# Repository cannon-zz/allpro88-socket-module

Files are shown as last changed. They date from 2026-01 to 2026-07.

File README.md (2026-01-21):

# KiCad Model of Logical Devices' ALLPRO88 PLCC Socket Module

## Overview

This provides a KiCad [schematic](https://github.com/user-attachments/files/24761395/socket_module_plcc_schematic.pdf) of the PLCC socket module for use with Logic Devices' ALLPRO88 software-driven device programmer.  The service manual scans available on the internet are incomprehensible.  I believe the schematic is correct.  The PCB's size and the locations of the DIN connectors, 48 pin ZIF connector and decoupling capacitors and transistors all match the original.  All other part locations are approximate, the PCB has not been routed, and the footprints for the PLCC sockets are not correct.  The PLCC sockets here have the wrong hole pattern, and are mirrored with respect to the originals.  The original module used Yamaichi IC120 series sockets, the "dead bug" variants (for which the chips are inserted upside down).  See a datasheet for the correct hole patterns.  The objective is not to allow a PLCC socket module to be reproduced from this project, but to provide a starting point for making a custom socket module.

## Board Size

Measuring my PCB to the nearest 0.5 mm, the PCB is 25.70 cm x 20.45 cm.

If it's imperial, and we allow some +/- for the saw cut accuracy, it could be 10 1/8" x 8" (= 25.7175 cm x 20.32 cm).

I found a comment in the service manual that the PCB is 10.100" x 8.05x" (x is unreadable, could be 0, 6 or 8 maybe).  0.001" = 0.0254 mm, so I don't think it really matters if that digit is a 0 or an 8.  10.1" x 8.05" = 25.65 cm x 20.45 cm which is within 0.5 mm of my measurements.

## DIN Connector Placement

From the corner of the PCB closest to the 44 pin PLCC socket, I mesaure pin C32 of J1 to be 100.8 mm horizontally from that corner, and 67.2 mm vertically.  The two DIN connectors appear to be positioned with respect to each other on a 2.54 mm grid:  A1 to A1 is 18 * 2.54 mm = 45.72 mm.  The status LEDs and their resistors appear to be on a 2.54 mm grid, centred between the DIN connectors

I suggest plugging the DIN connectors into the base, then placing the PCB onto them and either tightening the screws to hold them in that position or soldering enough pins to secure them, then removing the PCB with the connectors to continue soldering.  That way they're guaranteed to be aligned with their sockets after being soldered into position.

## Signal Names

The scans available on the internet of the original schematic, both for the socket module and the programmer's mother board, are incomprehensible.  Also, there are several inconsistent channel numbering schemes in Logical Devices' original documentation.  So:  what's here is my own invention.  Make of it what you will.

 * GND:  system power supply return.
 * -8 V, -5 V, +5 V, +12V, VREF:  main system power supplies.
 * VADJ:  main programmable, high current, power supply.  All pin driver voltages are derived from this.
 * VSR, VTH, VPU, ILIN:  pin driver power supplies.
 * !SOCKETEN:  active-low device select line indicating that the address bus is in the range 0x0280 to 0x02ff inclusively.  This is a 128 byte window reserved for the socket module.  On the universal PLCC module, reading from any address in this range returns the socket module ID, while writing to addresses in this range control the registers used to switch the pin decoupling capacitors on and off.
 * \phi_{0}, \phi_{1}:  the two phases used for driving the TTL clock output modes of the pin drivers.  When they are active they are guaranteed to be 180 degrees out of phase, but they can become inactive and enter the same state.
 * !XFER:  active low line to clock the pin driver DACs
 * !RD, !WR:  active low read- and write-enable signals.
 * !LED_BUSY, LED_IDLE:  common collector drives for the busy (red) and idle (green) LEDs.
 * !RESET:  active low system reset.  On the PLCC module, resets the decoupling capacitor registers to 0 (capacitors disconnected).
 * !SELECT0 -- !SELECT4:  active low device select lines for the first 5 pin driver modules, corresponding to channels 0 through 39 inclusively.  The ALLPRO88 was preceded by an earlier product that had only 40 channels, and it was presumably thought to be handy to have these signals brought out to the socket module to avoid duplicating address decoding circuitry in the event that lots of complex pin driver circuitry was needed for some part.
 * A0 -- A9:  partial system address bus.  The system address bus is 12 bits, but only the low 10 are present on the socket module.  Together with !SOCKETEN, only A0--A6 are needed to address the 128 byte window reserved for the socket module.
 * D0 -- D7:  system data bus.
 * OUT0 -- OUT87:  the 88 pin driver inputs/outputs.
 * SPARE1:  unused signal line that connects to the socket module, all pin driver boards, and both analogue 1 and analogue 2.  There are two unused voltage DACs on analogue 2, and I think a sensible thing to do would be to jumper one of them to this in line, to provide an additional programmable voltage to the system.  For example, the fixed 5 V linear regulators that generate the "TTL" output voltage on the pin driver boards could be replaced with adjustable regulators programmed by this voltage, making it easier to support non- 5 V logic.

## PAL

The PAL device is a look-up table for chip select line decoding.  To (I assume) simplify trace routing, pin driver channels are connected to ZIF socket pins close to their location on the DIN connector, in groups of 8 with 4 on one side of the socket and 4 on the other, while decoupling capacitor transistor drivers are connected to transistors sequentially along each side of the socket.  Additionally, for (again I assume) historical reasons only the first 40 channels have sequential addresses, the final 8 are offset at slightly higher addresses.  Altogther, these conditions create a somewhat complex relationship between the numerical address on the address bus and which transistor on which FET chip should be turned on or off, which motivates the use of a programmable logic device.

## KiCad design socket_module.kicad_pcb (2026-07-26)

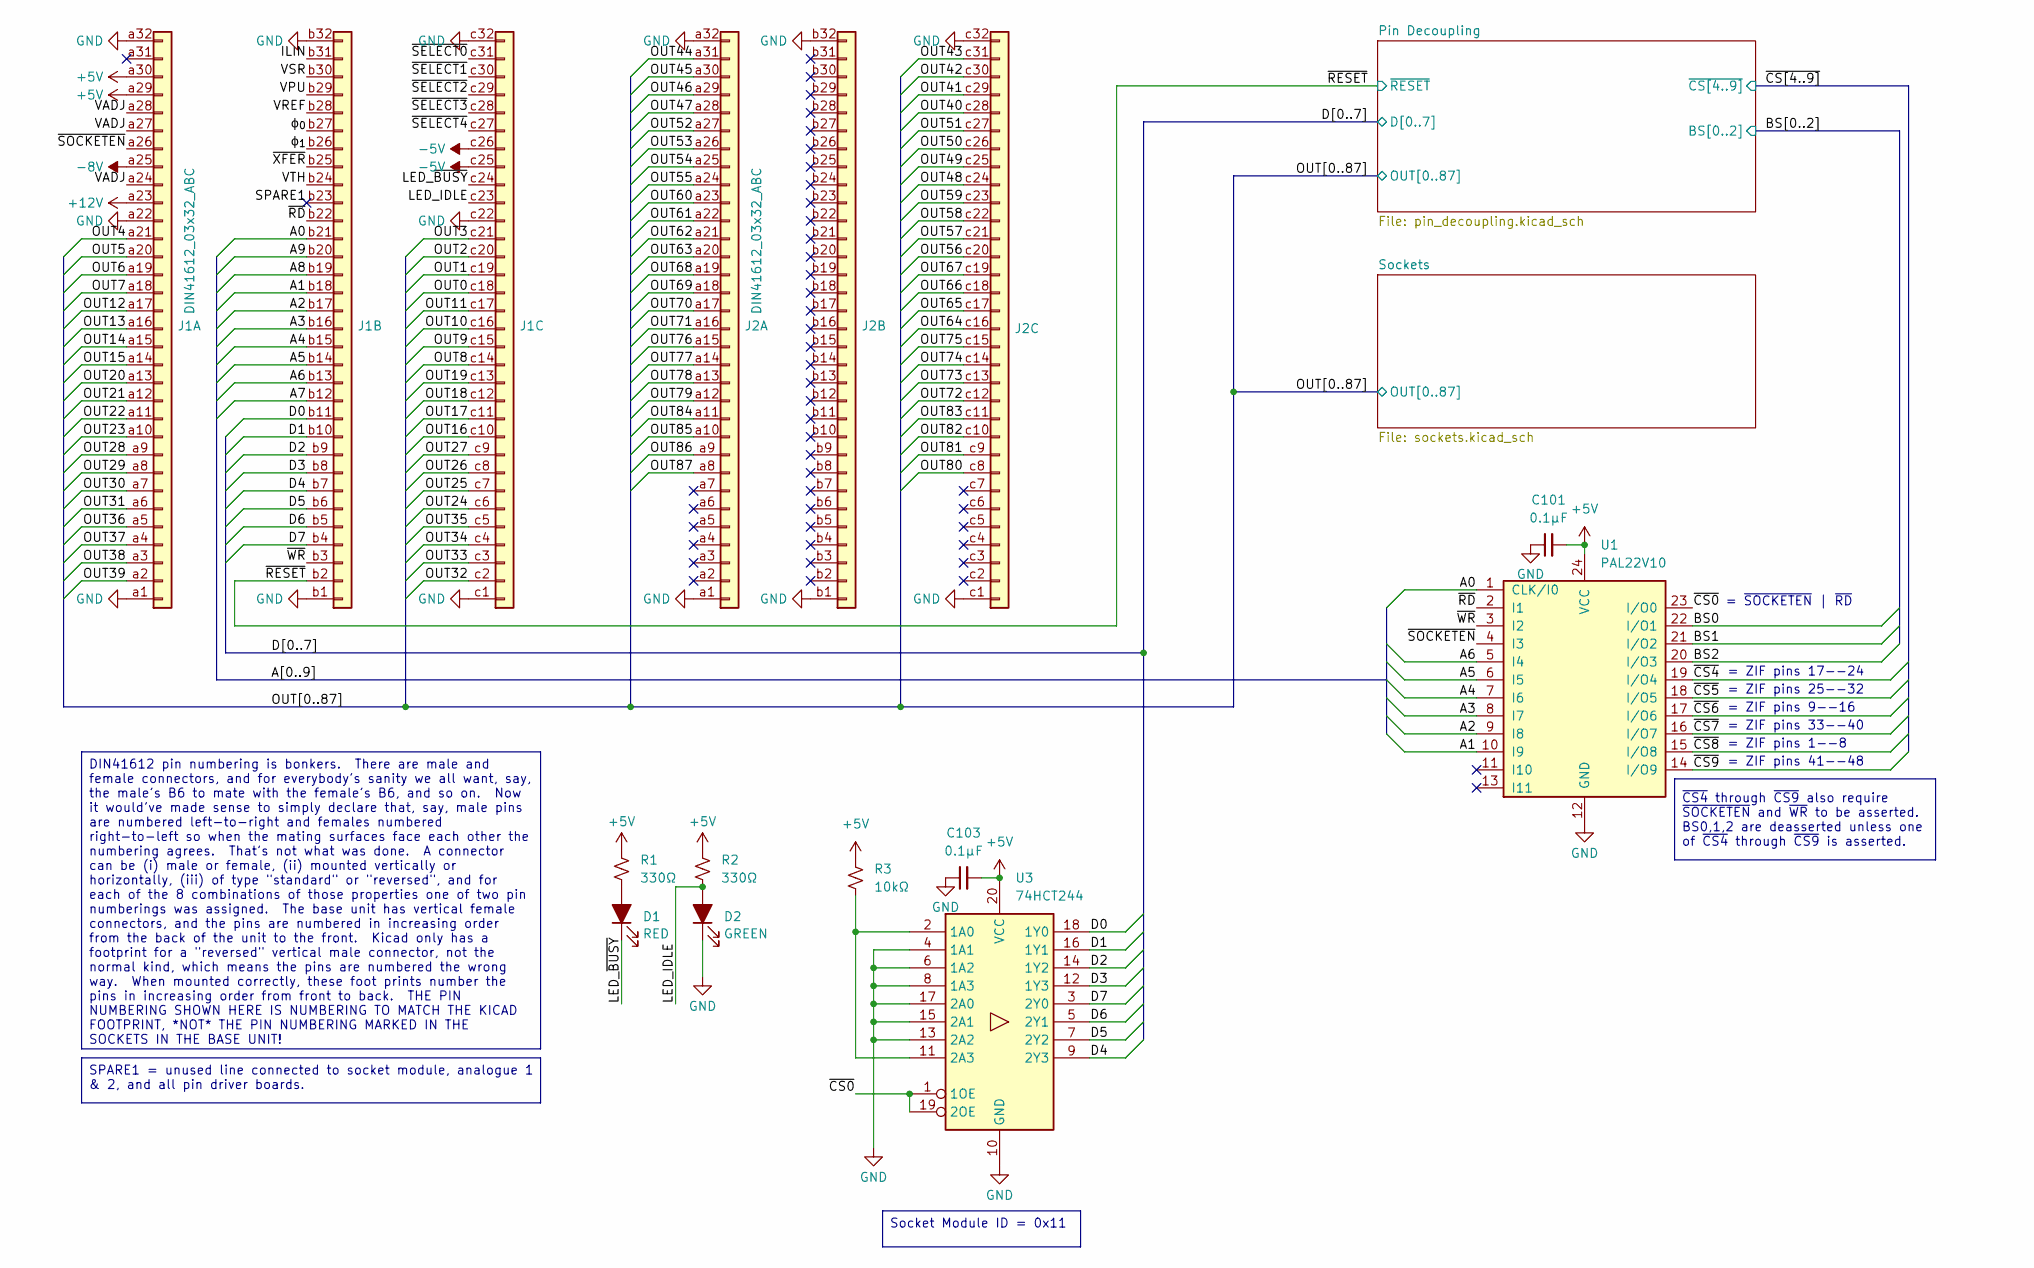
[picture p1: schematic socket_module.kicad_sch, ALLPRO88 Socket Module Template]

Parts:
C101, C103: 0.1μF; C_Disc_D7.5mm_W2.5mm_P5.00mm
D1: RED; LED_Rectangular_W5.0mm_H2.0mm
D2: GREEN; LED_Rectangular_W5.0mm_H2.0mm
J1, J2: DIN41612_03x32_ABC; DIN41612_R_3x32_Male_Vertical_THT
R1, R2: 330Ω; R_Axial_DIN0207_L6.3mm_D2.5mm_P10.16mm_Horizontal
R3: 10kΩ; R_Axial_DIN0207_L6.3mm_D2.5mm_P10.16mm_Horizontal
U1: PAL22V10; DIP-24_W7.62mm_Socket_LongPads
U3: 74HCT244; DIP-20_W7.62mm_LongPads

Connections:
+5V: C101.2, C103.2, J1.a29, J1.a30, R1.1, R2.1, R3.1, U1.24 (VCC), U3.20 (VCC); also elsewhere on the board
+12V: J1.a23
-5V: J1.c25, J1.c26
-8V: J1.a25
/A0: J1.b21, U1.1 (CLK/I0)
/A1: J1.b18, U1.10 (I9)
/A2: J1.b17, U1.9 (I8)
/A3: J1.b16, U1.8 (I7)
/A4: J1.b15, U1.7 (I6)
/A5: J1.b14, U1.6 (I5)
/A6: J1.b13, U1.5 (I4)
/A7: J1.b12
/A8: J1.b19
/A9: J1.b20
/BS0: U1.22 (I/O1); also elsewhere on the board
/BS1: U1.21 (I/O2); also elsewhere on the board
/BS2: U1.20 (I/O3); also elsewhere on the board
/D0: J1.b11, U3.18 (1Y0); also elsewhere on the board
/D1: J1.b10, U3.16 (1Y1)
/D2: J1.b9, U3.14 (1Y2)
/D3: J1.b8, U3.12 (1Y3)
/D4: J1.b7, U3.9 (2Y3)
/D5: J1.b6, U3.7 (2Y2)
/D6: J1.b5, U3.5 (2Y1)
/D7: J1.b4, U3.3 (2Y0)
/ILIN: J1.b31
/LED_IDLE: D2.2 (A), J1.c23, R2.2
/LED_~BUSY: D1.1 (K), J1.c24
/OUT0: J1.c18; also elsewhere on the board
/OUT1: J1.c19; also elsewhere on the board
/OUT2: J1.c20; also elsewhere on the board
/OUT3: J1.c21; also elsewhere on the board
/OUT4: J1.a21; also elsewhere on the board
/OUT5: J1.a20; also elsewhere on the board
/OUT6: J1.a19; also elsewhere on the board
/OUT7: J1.a18; also elsewhere on the board
/OUT8: J1.c14; also elsewhere on the board
/OUT9: J1.c15; also elsewhere on the board
/OUT10: J1.c16; also elsewhere on the board
/OUT11: J1.c17; also elsewhere on the board
/OUT12: J1.a17; also elsewhere on the board
/OUT13: J1.a16; also elsewhere on the board
/OUT14: J1.a15; also elsewhere on the board
/OUT15: J1.a14; also elsewhere on the board
/OUT16: J1.c10; also elsewhere on the board
/OUT17: J1.c11; also elsewhere on the board
/OUT18: J1.c12; also elsewhere on the board
/OUT19: J1.c13; also elsewhere on the board
/OUT20: J1.a13; also elsewhere on the board
/OUT21: J1.a12; also elsewhere on the board
/OUT22: J1.a11; also elsewhere on the board
/OUT23: J1.a10; also elsewhere on the board
/OUT24: J1.c6; also elsewhere on the board
/OUT25: J1.c7; also elsewhere on the board
/OUT26: J1.c8; also elsewhere on the board
/OUT27: J1.c9; also elsewhere on the board
/OUT28: J1.a9; also elsewhere on the board
/OUT29: J1.a8; also elsewhere on the board
/OUT30: J1.a7; also elsewhere on the board
/OUT31: J1.a6; also elsewhere on the board
/OUT32: J1.c2; also elsewhere on the board
/OUT33: J1.c3; also elsewhere on the board
/OUT34: J1.c4; also elsewhere on the board
/OUT35: J1.c5; also elsewhere on the board
/OUT36: J1.a5; also elsewhere on the board
/OUT37: J1.a4; also elsewhere on the board
/OUT38: J1.a3; also elsewhere on the board
/OUT39: J1.a2; also elsewhere on the board
/OUT40: J2.c28; also elsewhere on the board
/OUT41: J2.c29; also elsewhere on the board
/OUT42: J2.c30; also elsewhere on the board
/OUT43: J2.c31; also elsewhere on the board
/OUT44: J2.a31; also elsewhere on the board
/OUT45: J2.a30; also elsewhere on the board
/OUT46: J2.a29; also elsewhere on the board
/OUT47: J2.a28; also elsewhere on the board
/OUT48: J2.c24; also elsewhere on the board
/OUT49: J2.c25; also elsewhere on the board
/OUT50: J2.c26; also elsewhere on the board
/OUT51: J2.c27; also elsewhere on the board
/OUT52: J2.a27; also elsewhere on the board
/OUT53: J2.a26; also elsewhere on the board
/OUT54: J2.a25; also elsewhere on the board
/OUT55: J2.a24; also elsewhere on the board
/OUT56: J2.c20; also elsewhere on the board
/OUT57: J2.c21; also elsewhere on the board
/OUT58: J2.c22; also elsewhere on the board
/OUT59: J2.c23; also elsewhere on the board
/OUT60: J2.a23; also elsewhere on the board
/OUT61: J2.a22; also elsewhere on the board
/OUT62: J2.a21; also elsewhere on the board
/OUT63: J2.a20; also elsewhere on the board
/OUT64: J2.c16; also elsewhere on the board
/OUT65: J2.c17; also elsewhere on the board
/OUT66: J2.c18; also elsewhere on the board
/OUT67: J2.c19; also elsewhere on the board
/OUT68: J2.a19; also elsewhere on the board
/OUT69: J2.a18; also elsewhere on the board
/OUT70: J2.a17; also elsewhere on the board
/OUT71: J2.a16; also elsewhere on the board
/OUT72: J2.c12; also elsewhere on the board
/OUT73: J2.c13; also elsewhere on the board
/OUT74: J2.c14; also elsewhere on the board
/OUT75: J2.c15; also elsewhere on the board
/OUT76: J2.a15; also elsewhere on the board
/OUT77: J2.a14; also elsewhere on the board
/OUT78: J2.a13; also elsewhere on the board
/OUT79: J2.a12; also elsewhere on the board
/OUT80: J2.c8
/OUT81: J2.c9
/OUT82: J2.c10; also elsewhere on the board
/OUT83: J2.c11; also elsewhere on the board
/OUT84: J2.a11; also elsewhere on the board
/OUT85: J2.a10; also elsewhere on the board
/OUT86: J2.a9
/OUT87: J2.a8
/SPARE1: J1.b23
/VADJ: J1.a24, J1.a27, J1.a28
/VPU: J1.b29
/VREF: J1.b28
/VSR: J1.b30
/VTH: J1.b24 (Pin_a24)
/~CS0: U1.23 (I/O0), U3.1 (1OE), U3.19 (2OE)
/~CS4: U1.19 (I/O4); also elsewhere on the board
/~CS5: U1.18 (I/O5); also elsewhere on the board
/~CS6: U1.17 (I/O6); also elsewhere on the board
/~CS7: U1.16 (I/O7); also elsewhere on the board
/~CS8: U1.15 (I/O8); also elsewhere on the board
/~CS9: U1.14 (I/O9); also elsewhere on the board
/~RD: J1.b22, U1.2 (I1)
/~RESET: J1.b2; also elsewhere on the board
/~SELECT0: J1.c31
/~SELECT1: J1.c30
/~SELECT2: J1.c29
/~SELECT3: J1.c28
/~SELECT4: J1.c27
/~SOCKETEN: J1.a26, U1.4 (I3)
/~WR: J1.b3, U1.3 (I2)
/~XFER: J1.b25
/ϕ_{0}: J1.b27
/ϕ_{1}: J1.b26
GND: C101.1, C103.1, D2.1 (K), J1.a1, J1.a22, J1.a32, J1.b1, J1.b32, J1.c1, J1.c22, J1.c32, J2.a1, J2.a32, J2.b1, J2.b32, J2.c1, J2.c32, U1.12 (GND), U3.4 (1A1), U3.6 (1A2), U3.8 (1A3), U3.10 (GND), U3.13 (2A2), U3.15 (2A1), U3.17 (2A0); also elsewhere on the board
unnamed: D1.2 (A), R1.2
unnamed: R3.2, U3.2 (1A0), U3.11 (2A3)

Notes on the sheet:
= ZIF pins 33--40
= ~{SOCKETEN} | ~{RD}
= ZIF pins 17--24
= ZIF pins 41--48
= ZIF pins 1--8
= ZIF pins 25--32
= ZIF pins 9--16
~{CS4} through ~{CS9} also require ~{SOCKETEN} and ~{WR} to be asserted. BS0,1,2 are deasserted unless one of ~{CS4} through ~{CS9} is asserted.
Socket Module ID = 0x11
DIN41612 pin numbering is bonkers. There are male and female connectors, and for everybody's sanity we all want, say, the male's B6 to mate with the female's B6, and so on. Now it would've made sense to simply declare that, say, male pins are numbered left-to-right and females numbered right-to-lef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
SPARE1 = unused line connected to socket module, analogue 1 & 2, and all pin driver boards.

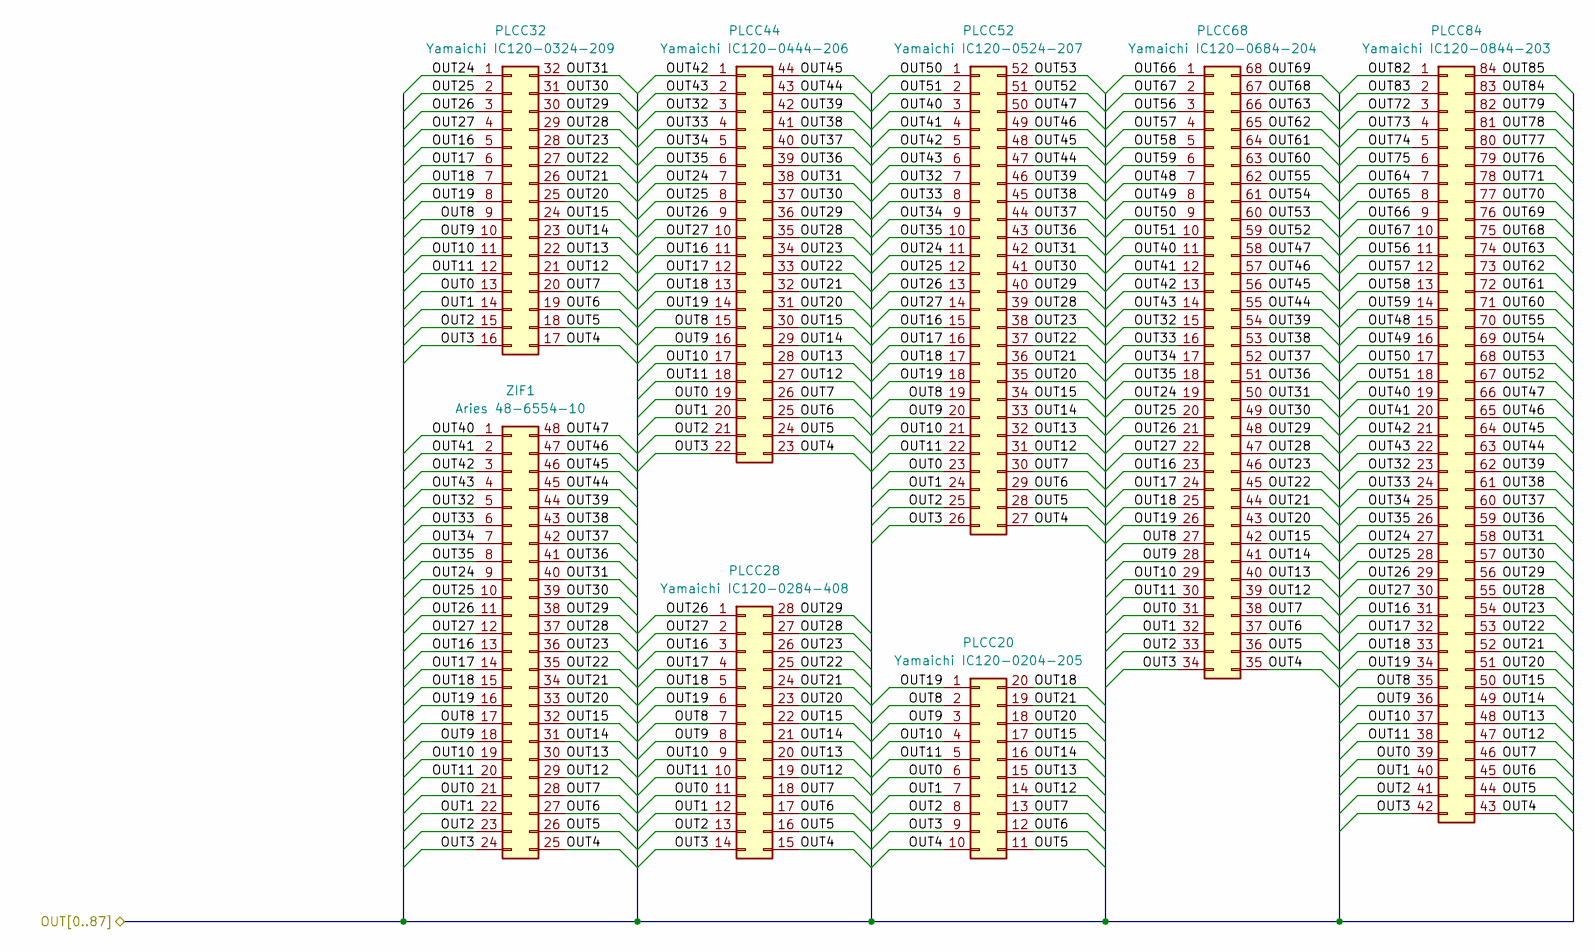
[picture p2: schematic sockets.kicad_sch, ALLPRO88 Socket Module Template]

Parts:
PLCC20: Yamaichi IC120-0204-205; PLCC-20_THT-Socket
PLCC28: Yamaichi IC120-0284-408; PLCC-28_THT-Socket
PLCC32: Yamaichi IC120-0324-209; PLCC-32_THT-Socket
PLCC44: Yamaichi IC120-0444-206; PLCC-44_THT-Socket
PLCC52: Yamaichi IC120-0524-207; PLCC-52_THT-Socket
PLCC68: Yamaichi IC120-0684-204; PLCC-68_THT-Socket
PLCC84: Yamaichi IC120-0844-203; PLCC-84_THT-Socket
ZIF1: Aries 48-6554-10; DIP-48_W15.24mm_Socket_LongPads

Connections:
/OUT0: PLCC20.6, PLCC28.11, PLCC32.13, PLCC44.19, PLCC52.23, PLCC68.31, PLCC84.39, ZIF1.21; also elsewhere on the board
/OUT1: PLCC20.7, PLCC28.12, PLCC32.14, PLCC44.20, PLCC52.24, PLCC68.32, PLCC84.40, ZIF1.22; also elsewhere on the board
/OUT2: PLCC20.8, PLCC28.13, PLCC32.15, PLCC44.21, PLCC52.25, PLCC68.33, PLCC84.41, ZIF1.23; also elsewhere on the board
/OUT3: PLCC20.9, PLCC28.14, PLCC32.16, PLCC44.22, PLCC52.26, PLCC68.34, PLCC84.42, ZIF1.24; also elsewhere on the board
/OUT4: PLCC20.10, PLCC28.15, PLCC32.17, PLCC44.23, PLCC52.27, PLCC68.35, PLCC84.43, ZIF1.25; also elsewhere on the board
/OUT5: PLCC20.11, PLCC28.16, PLCC32.18, PLCC44.24, PLCC52.28, PLCC68.36, PLCC84.44, ZIF1.26; also elsewhere on the board
/OUT6: PLCC20.12, PLCC28.17, PLCC32.19, PLCC44.25, PLCC52.29, PLCC68.37, PLCC84.45, ZIF1.27; also elsewhere on the board
/OUT7: PLCC20.13, PLCC28.18, PLCC32.20, PLCC44.26, PLCC52.30, PLCC68.38, PLCC84.46, ZIF1.28; also elsewhere on the board
/OUT8: PLCC20.2, PLCC28.7, PLCC32.9, PLCC44.15, PLCC52.19, PLCC68.27, PLCC84.35, ZIF1.17; also elsewhere on the board
/OUT9: PLCC20.3, PLCC28.8, PLCC32.10, PLCC44.16, PLCC52.20, PLCC68.28, PLCC84.36, ZIF1.18; also elsewhere on the board
/OUT10: PLCC20.4, PLCC28.9, PLCC32.11, PLCC44.17, PLCC52.21, PLCC68.29, PLCC84.37, ZIF1.19; also elsewhere on the board
/OUT11: PLCC20.5, PLCC28.10, PLCC32.12, PLCC44.18, PLCC52.22, PLCC68.30, PLCC84.38, ZIF1.20; also elsewhere on the board
/OUT12: PLCC20.14, PLCC28.19, PLCC32.21, PLCC44.27, PLCC52.31, PLCC68.39, PLCC84.47, ZIF1.29; also elsewhere on the board
/OUT13: PLCC20.15, PLCC28.20, PLCC32.22, PLCC44.28, PLCC52.32, PLCC68.40, PLCC84.48, ZIF1.30; also elsewhere on the board
/OUT14: PLCC20.16, PLCC28.21, PLCC32.23, PLCC44.29, PLCC52.33, PLCC68.41, PLCC84.49, ZIF1.31; also elsewhere on the board
/OUT15: PLCC20.17, PLCC28.22, PLCC32.24, PLCC44.30, PLCC52.34, PLCC68.42, PLCC84.50, ZIF1.32; also elsewhere on the board
/OUT16: PLCC28.3, PLCC32.5, PLCC44.11, PLCC52.15, PLCC68.23, PLCC84.31, ZIF1.13; also elsewhere on the board
/OUT17: PLCC28.4, PLCC32.6, PLCC44.12, PLCC52.16, PLCC68.24, PLCC84.32, ZIF1.14; also elsewhere on the board
/OUT18: PLCC20.20, PLCC28.5, PLCC32.7, PLCC44.13, PLCC52.17, PLCC68.25, PLCC84.33, ZIF1.15; also elsewhere on the board
/OUT19: PLCC20.1, PLCC28.6, PLCC32.8, PLCC44.14, PLCC52.18, PLCC68.26, PLCC84.34, ZIF1.16; also elsewhere on the board
/OUT20: PLCC20.18, PLCC28.23, PLCC32.25, PLCC44.31, PLCC52.35, PLCC68.43, PLCC84.51, ZIF1.33; also elsewhere on the board
/OUT21: PLCC20.19, PLCC28.24, PLCC32.26, PLCC44.32, PLCC52.36, PLCC68.44, PLCC84.52, ZIF1.34; also elsewhere on the board
/OUT22: PLCC28.25, PLCC32.27, PLCC44.33, PLCC52.37, PLCC68.45, PLCC84.53, ZIF1.35; also elsewhere on the board
/OUT23: PLCC28.26, PLCC32.28, PLCC44.34, PLCC52.38, PLCC68.46, PLCC84.54, ZIF1.36; also elsewhere on the board
/OUT24: PLCC32.1, PLCC44.7, PLCC52.11, PLCC68.19, PLCC84.27, ZIF1.9; also elsewhere on the board
/OUT25: PLCC32.2, PLCC44.8, PLCC52.12, PLCC68.20, PLCC84.28, ZIF1.10; also elsewhere on the board
/OUT26: PLCC28.1, PLCC32.3, PLCC44.9, PLCC52.13, PLCC68.21, PLCC84.29, ZIF1.11; also elsewhere on the board
/OUT27: PLCC28.2, PLCC32.4, PLCC44.10, PLCC52.14, PLCC68.22, PLCC84.30, ZIF1.12; also elsewhere on the board
/OUT28: PLCC28.27, PLCC32.29, PLCC44.35, PLCC52.39, PLCC68.47, PLCC84.55, ZIF1.37; also elsewhere on the board
/OUT29: PLCC28.28, PLCC32.30, PLCC44.36, PLCC52.40, PLCC68.48, PLCC84.56, ZIF1.38; also elsewhere on the board
/OUT30: PLCC32.31, PLCC44.37, PLCC52.41, PLCC68.49, PLCC84.57, ZIF1.39; also elsewhere on the board
/OUT31: PLCC32.32, PLCC44.38, PLCC52.42, PLCC68.50, PLCC84.58, ZIF1.40; also elsewhere on the board
/OUT32: PLCC44.3, PLCC52.7, PLCC68.15, PLCC84.23, ZIF1.5; also elsewhere on the board
/OUT33: PLCC44.4, PLCC52.8, PLCC68.16, PLCC84.24, ZIF1.6; also elsewhere on the board
/OUT34: PLCC44.5, PLCC52.9, PLCC68.17, PLCC84.25, ZIF1.7; also elsewhere on the board
/OUT35: PLCC44.6, PLCC52.10, PLCC68.18, PLCC84.26, ZIF1.8; also elsewhere on the board
/OUT36: PLCC44.39, PLCC52.43, PLCC68.51, PLCC84.59, ZIF1.41; also elsewhere on the board
/OUT37: PLCC44.40, PLCC52.44, PLCC68.52, PLCC84.60, ZIF1.42; also elsewhere on the board
/OUT38: PLCC44.41, PLCC52.45, PLCC68.53, PLCC84.61, ZIF1.43; also elsewhere on the board
/OUT39: PLCC44.42, PLCC52.46, PLCC68.54, PLCC84.62, ZIF1.44; also elsewhere on the board
/OUT40: PLCC52.3, PLCC68.11, PLCC84.19, ZIF1.1; also elsewhere on the board
/OUT41: PLCC52.4, PLCC68.12, PLCC84.20, ZIF1.2; also elsewhere on the board
/OUT42: PLCC44.1, PLCC52.5, PLCC68.13, PLCC84.21, ZIF1.3; also elsewhere on the board
/OUT43: PLCC44.2, PLCC52.6, PLCC68.14, PLCC84.22, ZIF1.4; also elsewhere on the board
/OUT44: PLCC44.43, PLCC52.47, PLCC68.55, PLCC84.63, ZIF1.45; also elsewhere on the board
/OUT45: PLCC44.44, PLCC52.48, PLCC68.56, PLCC84.64, ZIF1.46; also elsewhere on the board
/OUT46: PLCC52.49, PLCC68.57, PLCC84.65, ZIF1.47; also elsewhere on the board
/OUT47: PLCC52.50, PLCC68.58, PLCC84.66, ZIF1.48; also elsewhere on the board
/OUT48: PLCC68.7, PLCC84.15; also elsewhere on the board
/OUT49: PLCC68.8, PLCC84.16; also elsewhere on the board
/OUT50: PLCC52.1, PLCC68.9, PLCC84.17; also elsewhere on the board
/OUT51: PLCC52.2, PLCC68.10, PLCC84.18; also elsewhere on the board
/OUT52: PLCC52.51, PLCC68.59, PLCC84.67; also elsewhere on the board
/OUT53: PLCC52.52, PLCC68.60, PLCC84.68; also elsewhere on the board
/OUT54: PLCC68.61, PLCC84.69; also elsewhere on the board
/OUT55: PLCC68.62, PLCC84.70; also elsewhere on the board
/OUT56: PLCC68.3, PLCC84.11; also elsewhere on the board
/OUT57: PLCC68.4, PLCC84.12; also elsewhere on the board
/OUT58: PLCC68.5, PLCC84.13; also elsewhere on the board
/OUT59: PLCC68.6, PLCC84.14; also elsewhere on the board
/OUT60: PLCC68.63, PLCC84.71; also elsewhere on the board
/OUT61: PLCC68.64, PLCC84.72; also elsewhere on the board
/OUT62: PLCC68.65, PLCC84.73; also elsewhere on the board
/OUT63: PLCC68.66, PLCC84.74; also elsewhere on the board
/OUT64: PLCC84.7; also elsewhere on the board
/OUT65: PLCC84.8; also elsewhere on the board
/OUT66: PLCC68.1, PLCC84.9; also elsewhere on the board
/OUT67: PLCC68.2, PLCC84.10; also elsewhere on the board
/OUT68: PLCC68.67, PLCC84.75; also elsewhere on the board
/OUT69: PLCC68.68, PLCC84.76; also elsewhere on the board
/OUT70: PLCC84.77; also elsewhere on the board
/OUT71: PLCC84.78; also elsewhere on the board
/OUT72: PLCC84.3; also elsewhere on the board
/OUT73: PLCC84.4; also elsewhere on the board
/OUT74: PLCC84.5; also elsewhere on the board
/OUT75: PLCC84.6; also elsewhere on the board
/OUT76: PLCC84.79; also elsewhere on the board
/OUT77: PLCC84.80; also elsewhere on the board
/OUT78: PLCC84.81; also elsewhere on the board
/OUT79: PLCC84.82; also elsewhere on the board
/OUT82: PLCC84.1; also elsewhere on the board
/OUT83: PLCC84.2; also elsewhere on the board
/OUT84: PLCC84.83; also elsewhere on the board
/OUT85: PLCC84.84; also elsewhere on the board

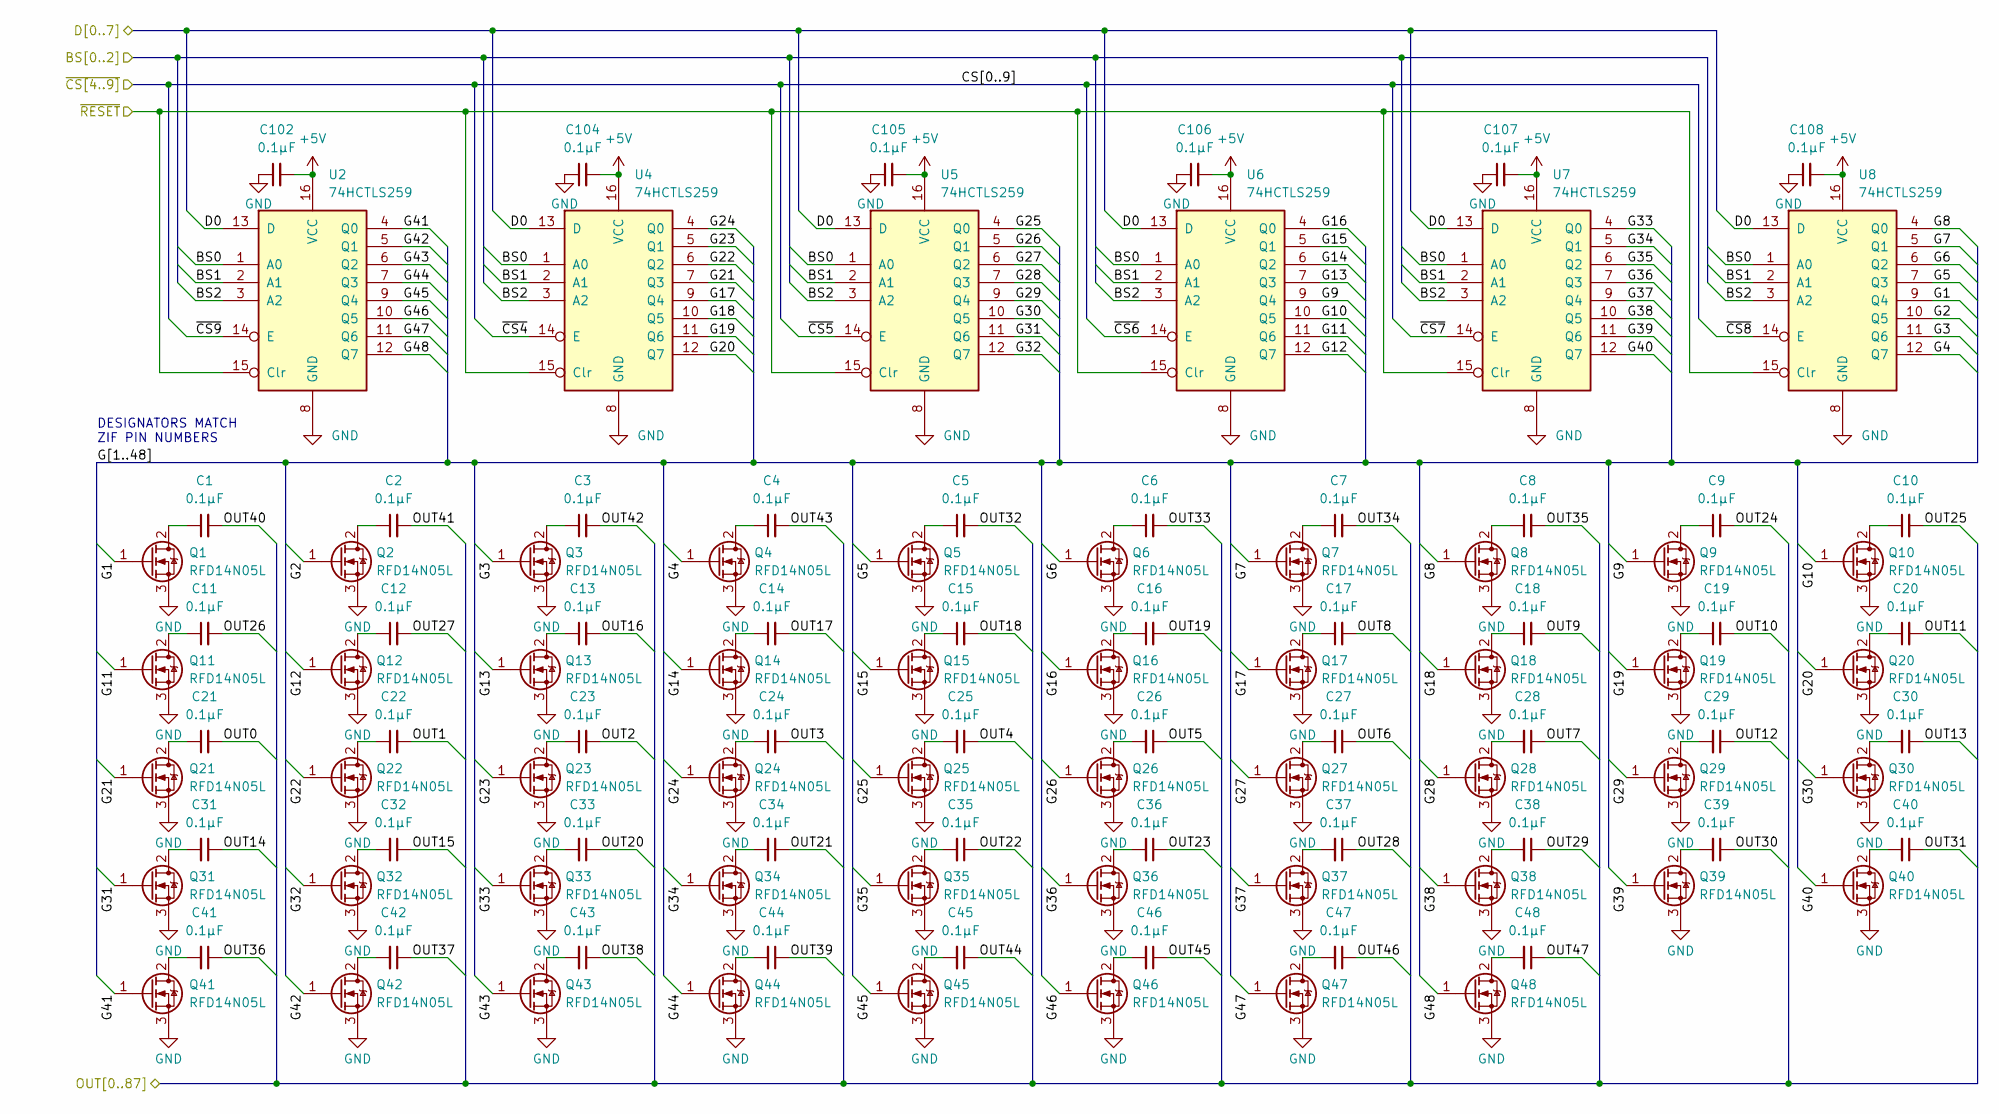
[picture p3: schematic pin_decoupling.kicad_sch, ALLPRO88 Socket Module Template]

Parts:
C1, C2, C3, C4, C5, C6, C7, C8, C9, C10, C11, C12, C13, C14, C15, C16, C17, C18, C19, C20, C21, C22, C23, C24, C25, C26, C27, C28, C29, C30, C31, C32, C33, C34, C35, C36, C37, C38, C39, C40, C41, C42, C43, C44, C45, C46, C47, C48, C102, C104, C105, C106, C107, C108: 0.1μF; C_Disc_D7.5mm_W2.5mm_P5.00mm
Q1, Q2, Q3, Q4, Q5, Q6, Q7, Q8, Q9, Q10, Q11, Q12, Q13, Q14, Q15, Q16, Q17, Q18, Q19, Q20, Q21, Q22, Q23, Q24, Q25, Q26, Q27, Q28, Q29, Q30, Q31, Q32, Q33, Q34, Q35, Q36, Q37, Q38, Q39, Q40, Q41, Q42, Q43, Q44, Q45, Q46, Q47, Q48: RFD14N05L; TO-251-3_Vertical
U2, U4, U5, U6, U7, U8: 74HCTLS259; DIP-16_W7.62mm_LongPads

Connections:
+5V: C102.2, C104.2, C105.2, C106.2, C107.2, C108.2, U2.16 (VCC), U4.16 (VCC), U5.16 (VCC), U6.16 (VCC), U7.16 (VCC), U8.16 (VCC); also elsewhere on the board
/BS0: U2.1 (A0), U4.1 (A0), U5.1 (A0), U6.1 (A0), U7.1 (A0), U8.1 (A0); also elsewhere on the board
/BS1: U2.2 (A1), U4.2 (A1), U5.2 (A1), U6.2 (A1), U7.2 (A1), U8.2 (A1); also elsewhere on the board
/BS2: U2.3 (A2), U4.3 (A2), U5.3 (A2), U6.3 (A2), U7.3 (A2), U8.3 (A2); also elsewhere on the board
/D0: U2.13 (D), U4.13 (D), U5.13 (D), U6.13 (D), U7.13 (D), U8.13 (D); also elsewhere on the board
/OUT0: C21.2; also elsewhere on the board
/OUT1: C22.2; also elsewhere on the board
/OUT2: C23.2; also elsewhere on the board
/OUT3: C24.2; also elsewhere on the board
/OUT4: C25.1; also elsewhere on the board
/OUT5: C26.1; also elsewhere on the board
/OUT6: C27.1; also elsewhere on the board
/OUT7: C28.1; also elsewhere on the board
/OUT8: C17.2; also elsewhere on the board
/OUT9: C18.2; also elsewhere on the board
/OUT10: C19.2; also elsewhere on the board
/OUT11: C20.2; also elsewhere on the board
/OUT12: C29.1; also elsewhere on the board
/OUT13: C30.1; also elsewhere on the board
/OUT14: C31.1; also elsewhere on the board
/OUT15: C32.1; also elsewhere on the board
/OUT16: C13.2; also elsewhere on the board
/OUT17: C14.2; also elsewhere on the board
/OUT18: C15.2; also elsewhere on the board
/OUT19: C16.2; also elsewhere on the board
/OUT20: C33.1; also elsewhere on the board
/OUT21: C34.1; also elsewhere on the board
/OUT22: C35.1; also elsewhere on the board
/OUT23: C36.1; also elsewhere on the board
/OUT24: C9.2; also elsewhere on the board
/OUT25: C10.2; also elsewhere on the board
/OUT26: C11.2; also elsewhere on the board
/OUT27: C12.2; also elsewhere on the board
/OUT28: C37.1; also elsewhere on the board
/OUT29: C38.1; also elsewhere on the board
/OUT30: C39.1; also elsewhere on the board
/OUT31: C40.1; also elsewhere on the board
/OUT32: C5.2; also elsewhere on the board
/OUT33: C6.2; also elsewhere on the board
/OUT34: C7.2; also elsewhere on the board
/OUT35: C8.2; also elsewhere on the board
/OUT36: C41.1; also elsewhere on the board
/OUT37: C42.1; also elsewhere on the board
/OUT38: C43.1; also elsewhere on the board
/OUT39: C44.1; also elsewhere on the board
/OUT40: C1.2; also elsewhere on the board
/OUT41: C2.2; also elsewhere on the board
/OUT42: C3.2; also elsewhere on the board
/OUT43: C4.2; also elsewhere on the board
/OUT44: C45.1; also elsewhere on the board
/OUT45: C46.1; also elsewhere on the board
/OUT46: C47.1; also elsewhere on the board
/OUT47: C48.1; also elsewhere on the board
/Pin Decoupling/G1: Q1.1 (G), U8.9 (Q4)
/Pin Decoupling/G2: Q2.1 (G), U8.10 (Q5)
/Pin Decoupling/G3: Q3.1 (G), U8.11 (Q6)
/Pin Decoupling/G4: Q4.1 (G), U8.12 (Q7)
/Pin Decoupling/G5: Q5.1 (G), U8.7 (Q3)
/Pin Decoupling/G6: Q6.1 (G), U8.6 (Q2)
/Pin Decoupling/G7: Q7.1 (G), U8.5 (Q1)
/Pin Decoupling/G8: Q8.1 (G), U8.4 (Q0)
/Pin Decoupling/G9: Q9.1 (G), U6.9 (Q4)
/Pin Decoupling/G10: Q10.1 (G), U6.10 (Q5)
/Pin Decoupling/G11: Q11.1 (G), U6.11 (Q6)
/Pin Decoupling/G12: Q12.1 (G), U6.12 (Q7)
/Pin Decoupling/G13: Q13.1 (G), U6.7 (Q3)
/Pin Decoupling/G14: Q14.1 (G), U6.6 (Q2)
/Pin Decoupling/G15: Q15.1 (G), U6.5 (Q1)
/Pin Decoupling/G16: Q16.1 (G), U6.4 (Q0)
/Pin Decoupling/G17: Q17.1 (G), U4.9 (Q4)
/Pin Decoupling/G18: Q18.1 (G), U4.10 (Q5)
/Pin Decoupling/G19: Q19.1 (G), U4.11 (Q6)
/Pin Decoupling/G20: Q20.1 (G), U4.12 (Q7)
/Pin Decoupling/G21: Q21.1 (G), U4.7 (Q3)
/Pin Decoupling/G22: Q22.1 (G), U4.6 (Q2)
/Pin Decoupling/G23: Q23.1 (G), U4.5 (Q1)
/Pin Decoupling/G24: Q24.1 (G), U4.4 (Q0)
/Pin Decoupling/G25: Q25.1 (G), U5.4 (Q0)
/Pin Decoupling/G26: Q26.1 (G), U5.5 (Q1)
/Pin Decoupling/G27: Q27.1 (G), U5.6 (Q2)
/Pin Decoupling/G28: Q28.1 (G), U5.7 (Q3)
/Pin Decoupling/G29: Q29.1 (G), U5.9 (Q4)
/Pin Decoupling/G30: Q30.1 (G), U5.10 (Q5)
/Pin Decoupling/G31: Q31.1 (G), U5.11 (Q6)
/Pin Decoupling/G32: Q32.1 (G), U5.12 (Q7)
/Pin Decoupling/G33: Q33.1 (G), U7.4 (Q0)
/Pin Decoupling/G34: Q34.1 (G), U7.5 (Q1)
/Pin Decoupling/G35: Q35.1 (G), U7.6 (Q2)
/Pin Decoupling/G36: Q36.1 (G), U7.7 (Q3)
/Pin Decoupling/G37: Q37.1 (G), U7.9 (Q4)
/Pin Decoupling/G38: Q38.1 (G), U7.10 (Q5)
/Pin Decoupling/G39: Q39.1 (G), U7.11 (Q6)
/Pin Decoupling/G40: Q40.1 (G), U7.12 (Q7)
/Pin Decoupling/G41: Q41.1 (G), U2.4 (Q0)
/Pin Decoupling/G42: Q42.1 (G), U2.5 (Q1)
/Pin Decoupling/G43: Q43.1 (G), U2.6 (Q2)
/Pin Decoupling/G44: Q44.1 (G), U2.7 (Q3)
/Pin Decoupling/G45: Q45.1 (G), U2.9 (Q4)
/Pin Decoupling/G46: Q46.1 (G), U2.10 (Q5)
/Pin Decoupling/G47: Q47.1 (G), U2.11 (Q6)
/Pin Decoupling/G48: Q48.1 (G), U2.12 (Q7)
/~CS4: U4.14 (E); also elsewhere on the board
/~CS5: U5.14 (E); also elsewhere on the board
/~CS6: U6.14 (E); also elsewhere on the board
/~CS7: U7.14 (E); also elsewhere on the board
/~CS8: U8.14 (E); also elsewhere on the board
/~CS9: U2.14 (E); also elsewhere on the board
/~RESET: U2.15 (Clr), U4.15 (Clr), U5.15 (Clr), U6.15 (Clr), U7.15 (Clr), U8.15 (Clr); also elsewhere on the board
GND: C102.1, C104.1, C105.1, C106.1, C107.1, C108.1, Q1.3 (S), Q2.3 (S), Q3.3 (S), Q4.3 (S), Q5.3 (S), Q6.3 (S), Q7.3 (S), Q8.3 (S), Q9.3 (S), Q10.3 (S), Q11.3 (S), Q12.3 (S), Q13.3 (S), Q14.3 (S), Q15.3 (S), Q16.3 (S), Q17.3 (S), Q18.3 (S), Q19.3 (S), Q20.3 (S), Q21.3 (S), Q22.3 (S), Q23.3 (S), Q24.3 (S), Q25.3 (S), Q26.3 (S), Q27.3 (S), Q28.3 (S), Q29.3 (S), Q30.3 (S), Q31.3 (S), Q32.3 (S), Q33.3 (S), Q34.3 (S), Q35.3 (S), Q36.3 (S), Q37.3 (S), Q38.3 (S), Q39.3 (S), Q40.3 (S), Q41.3 (S), Q42.3 (S), Q43.3 (S), Q44.3 (S), Q45.3 (S), Q46.3 (S), Q47.3 (S), Q48.3 (S), U2.8 (GND), U4.8 (GND), U5.8 (GND), U6.8 (GND), U7.8 (GND), U8.8 (GND); also elsewhere on the board
unnamed: C1.1, Q1.2 (D)
unnamed: C2.1, Q2.2 (D)
unnamed: C3.1, Q3.2 (D)
unnamed: C4.1, Q4.2 (D)
unnamed: C5.1, Q5.2 (D)
unnamed: C6.1, Q6.2 (D)
unnamed: C7.1, Q7.2 (D)
unnamed: C8.1, Q8.2 (D)
unnamed: C9.1, Q9.2 (D)
unnamed: C10.1, Q10.2 (D)
unnamed: C11.1, Q11.2 (D)
unnamed: C12.1, Q12.2 (D)
unnamed: C13.1, Q13.2 (D)
unnamed: C14.1, Q14.2 (D)
unnamed: C15.1, Q15.2 (D)
unnamed: C16.1, Q16.2 (D)
unnamed: C17.1, Q17.2 (D)
unnamed: C18.1, Q18.2 (D)
unnamed: C19.1, Q19.2 (D)
unnamed: C20.1, Q20.2 (D)
unnamed: C21.1, Q21.2 (D)
unnamed: C22.1, Q22.2 (D)
unnamed: C23.1, Q23.2 (D)
unnamed: C24.1, Q24.2 (D)
unnamed: C25.2, Q25.2 (D)
unnamed: C26.2, Q26.2 (D)
unnamed: C27.2, Q27.2 (D)
unnamed: C28.2, Q28.2 (D)
unnamed: C29.2, Q29.2 (D)
unnamed: C30.2, Q30.2 (D)
unnamed: C31.2, Q31.2 (D)
unnamed: C32.2, Q32.2 (D)
unnamed: C33.2, Q33.2 (D)
unnamed: C34.2, Q34.2 (D)
unnamed: C35.2, Q35.2 (D)
unnamed: C36.2, Q36.2 (D)
unnamed: C37.2, Q37.2 (D)
unnamed: C38.2, Q38.2 (D)
unnamed: C39.2, Q39.2 (D)
unnamed: C40.2, Q40.2 (D)
unnamed: C41.2, Q41.2 (D)
unnamed: C42.2, Q42.2 (D)
unnamed: C43.2, Q43.2 (D)
unnamed: C44.2, Q44.2 (D)
unnamed: C45.2, Q45.2 (D)
unnamed: C46.2, Q46.2 (D)
unnamed: C47.2, Q47.2 (D)
unnamed: C48.2, Q48.2 (D)

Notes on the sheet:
DESIGNATORS MATCH ZIF PIN NUMBERS

Board: 2 copper layers, 127 parts (10 on the bottom side), 217 nets, no tracks yet.

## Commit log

2025-05-29 original commit
    - the schematic should be exactly correct
    - the PCB size matches the PLCC socket module's PCB
    - the placement of the DIN connectors matches their locations on the PLCC socket module's PCB
    - the 48 pin ZIF socket is placed in the correct location WRT the DIN connectors
    - the decoupling capacitors and associated transistors are placed in the correct locations (except half of the transistors are rotated 180 degrees for convenience)
    - nothing else is positioned properly, it's just approximate, and there are no PCB traces.
    - the PLCC sockets are basically wrong: their footprints have the wrong pin pattern, and are mirrored because the original sockets are "dead bug" style (parts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
    [pin_decoupling.kicad_sch, socket_module.kicad_pcb, socket_module.kicad_sch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]
2025-05-30 README.md
    - add comment about board dimensions.
2025-05-30 README.md
    - fix link to schematic
2025-05-30 README.md:
    - add a description of the signals on the sockets
2025-06-02 updates:
    - update symbols and footprints from library
    - re-correct 84 pin PLCC pin numbers
    - reset transistors to TO-2whatever from SMD
    - adjust position of DIN connectors, LEDs and their resistors (and 48 pin DIP and transistors and decoupling capacitors): measured again.
    [pin_decoupling.kicad_sch, socket_module.kicad_pcb, socket_module.kicad_sch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]
2026-01-11 decoded PAL contents, added notes
    [pin_decoupling.kicad_sch, socket_module.kicad_pcb, socket_module.kicad_sch]
2026-01-21 update schematic PDF url
2026-07-26 update symbols and footprints with latest kicad
    [pin_decoupling.kicad_sch, socket_module.kicad_pcb, socket_module.kicad_sch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]
